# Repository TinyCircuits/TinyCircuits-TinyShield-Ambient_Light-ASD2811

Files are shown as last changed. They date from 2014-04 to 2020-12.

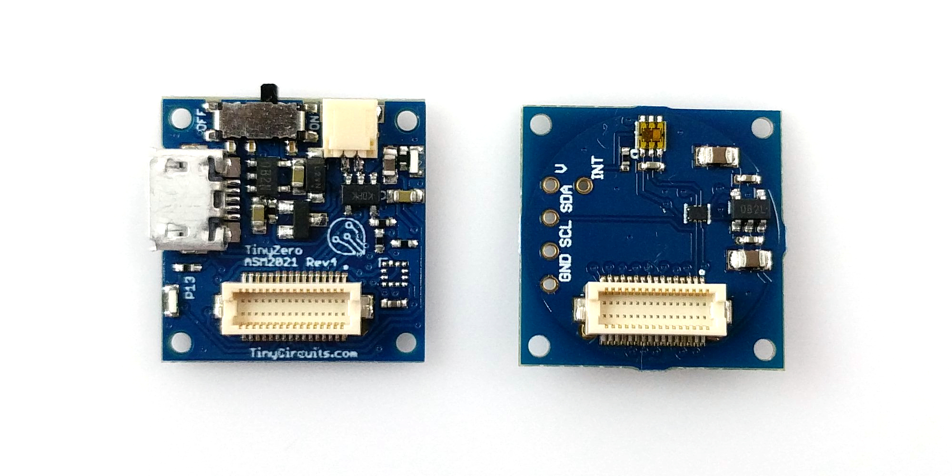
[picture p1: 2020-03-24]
images/ASD2811-R-Tutorial-Image-02.jpg

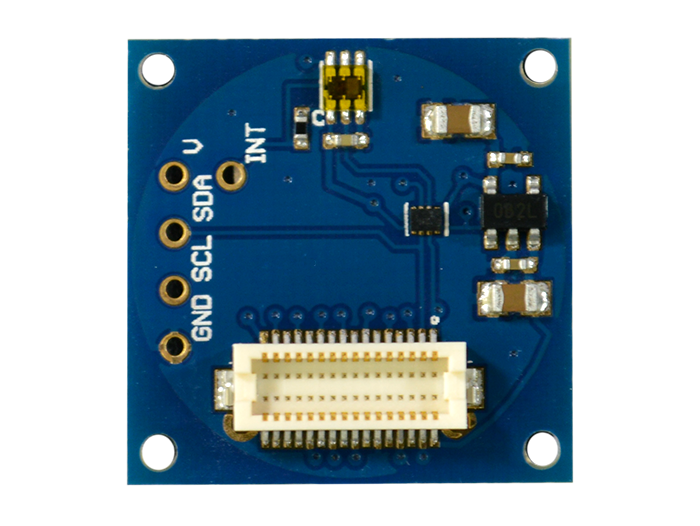
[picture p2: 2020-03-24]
images/ASD2811-R-Tutorial-Image-01.png

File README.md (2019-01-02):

# TinyCircuits TinyShield Ambient Light Sensor Board
# ASD2811 Rev2

The design files are located under design_files/ for the TinyCircuits ASD2811 Rev 2 PCB.  This is a TinyShield board (Square Version, 20mm x 20mm, or Circular 20mm diameter) that has a TAOS TSL2572 Ambient Light Sensor, local power supply and level shifters to connect between the TinyDuino and the accelerometer. 

Format is in Cadsoft Eagle format - Eagle version 6.2 was used for the original design.

For more infomation on this, check out the product page at TinyCircuits.com: https://tinycircuits.com/collections/sensors/products/ambient-light-tinyshield

#License:

Design by TinyCircuits.
All design files are released under the Creative Commons Attribution Share-Alike 3.0 License, see the following link for details: http://creativecommons.org/licenses/by-sa/3.0

All text above must be included in any redistribution or derived design

This project uses designs and concepts developed as part of the Arduino project and the LilyPad project.  The TinyCircuits design files themselves (schematics, PCB and libraries) are not directly derived from these works' design files and have been created new, however the concepts and basic architecture behind the TinyDuino and TinyLily products are derived and we thank the hard work of the organizations below for their contributions to open-source hardware:
  
Original Arduino Uno Design by Team Arduino

LilyPad Arduino Design by Leah Buechley and Sparkfun Electronics

Please support the open-source hardware community

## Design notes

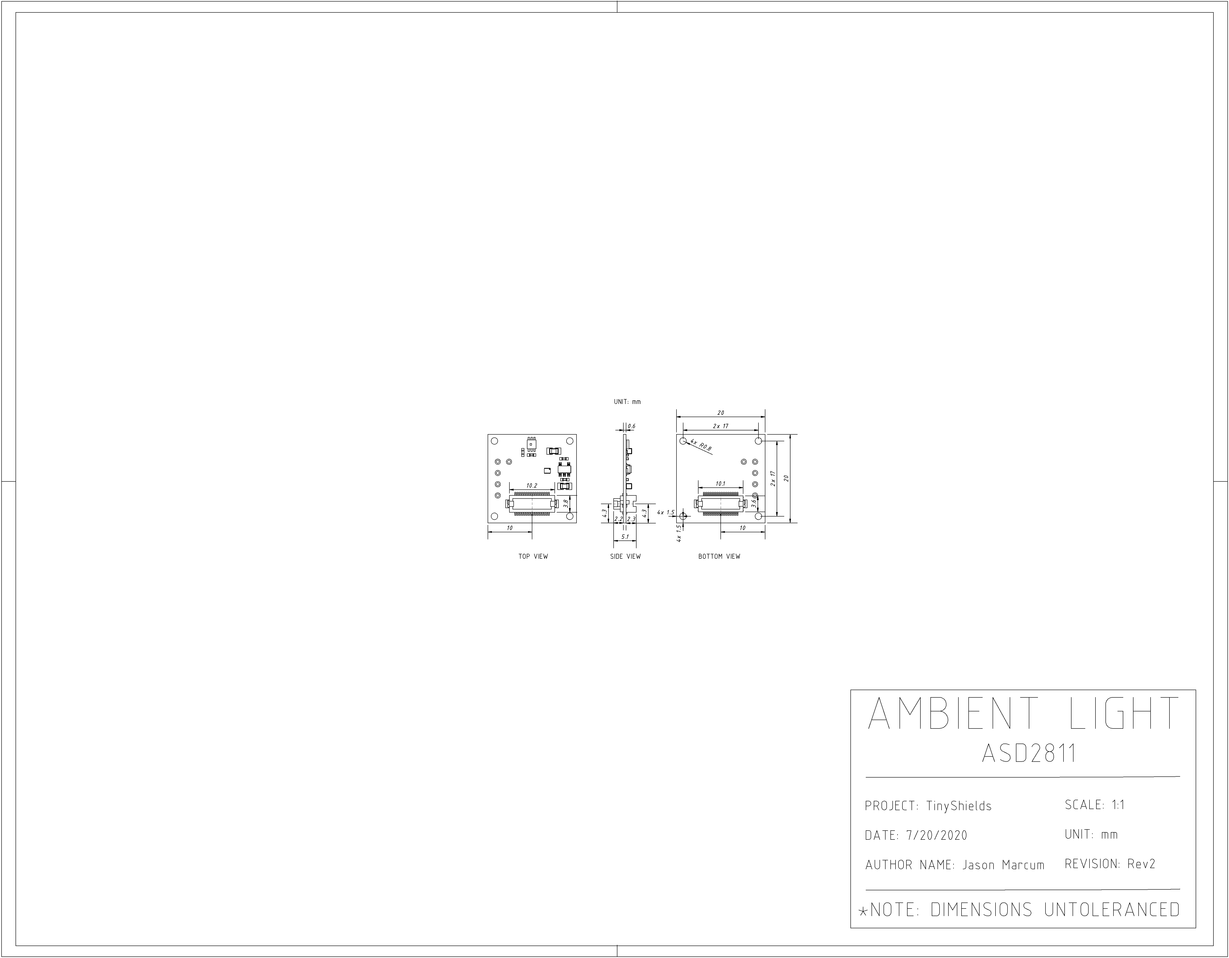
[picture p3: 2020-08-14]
cad/TinyShield_AMBIENT_LIGHT_ASD2811_REV2-DETAILED_DRAWING-PNG.png

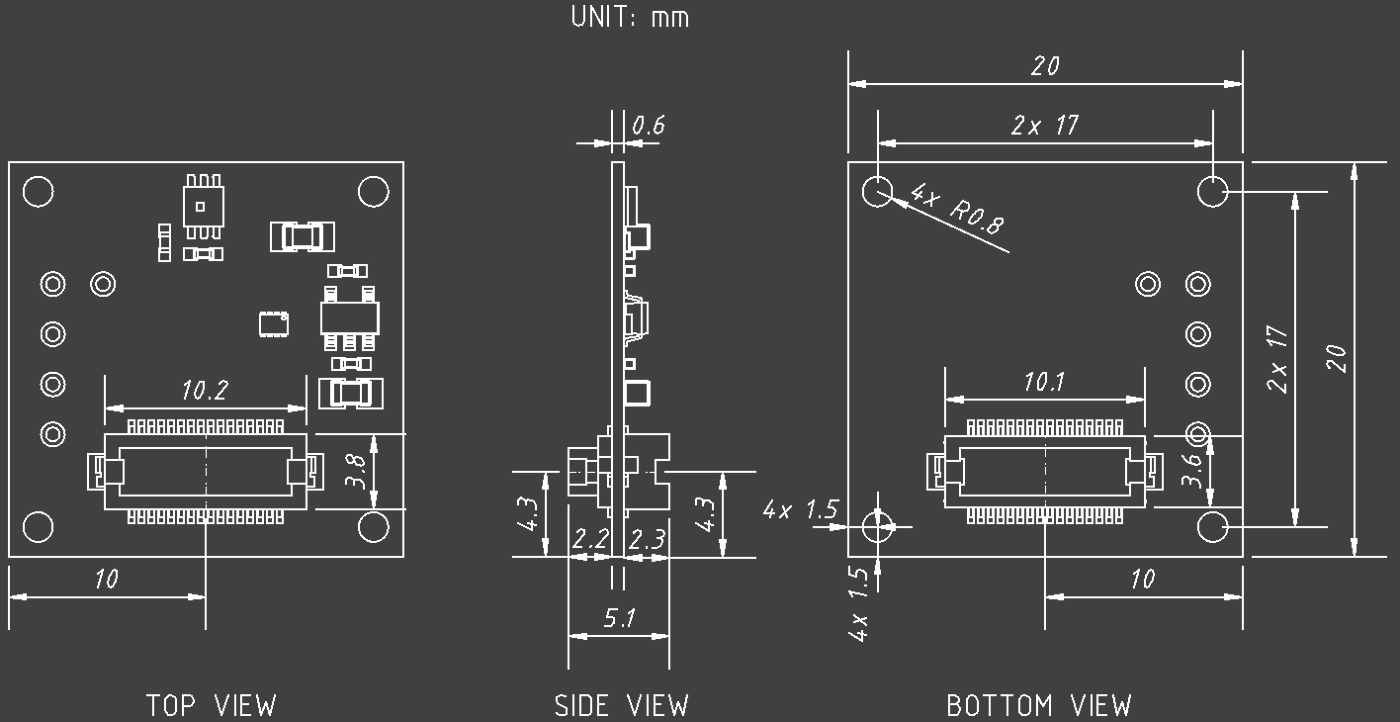
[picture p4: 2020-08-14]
cad/TinyShield_AMBIENT_LIGHT_ASD2811_REV2-DETAILED_DRAWING_COMPACT-PNG.png

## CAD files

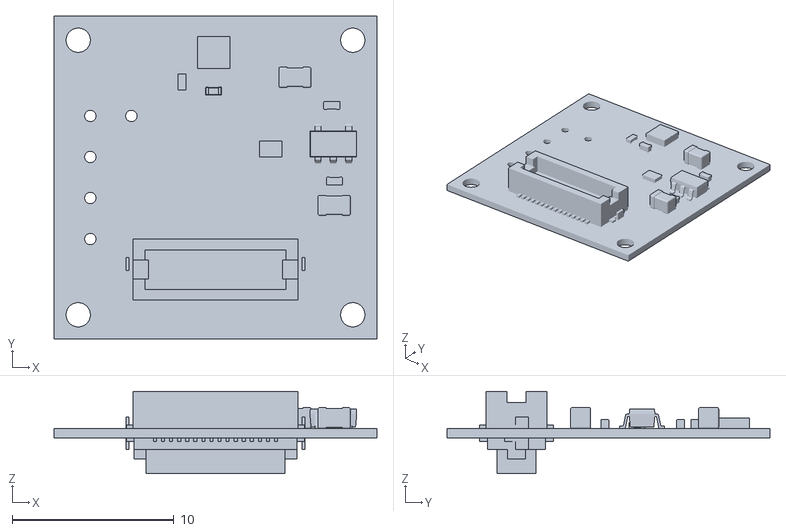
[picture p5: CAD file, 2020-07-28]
cad/TinyShield_AMBIENT_LIGHT_ASD2811_REV2-STL.stl
20.0 x 20.0 x 5.10

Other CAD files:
cad/TinyShield_AMBIENT_LIGHT_ASD2811_REV2-DETAILED_DRAWING-DXF.dxf

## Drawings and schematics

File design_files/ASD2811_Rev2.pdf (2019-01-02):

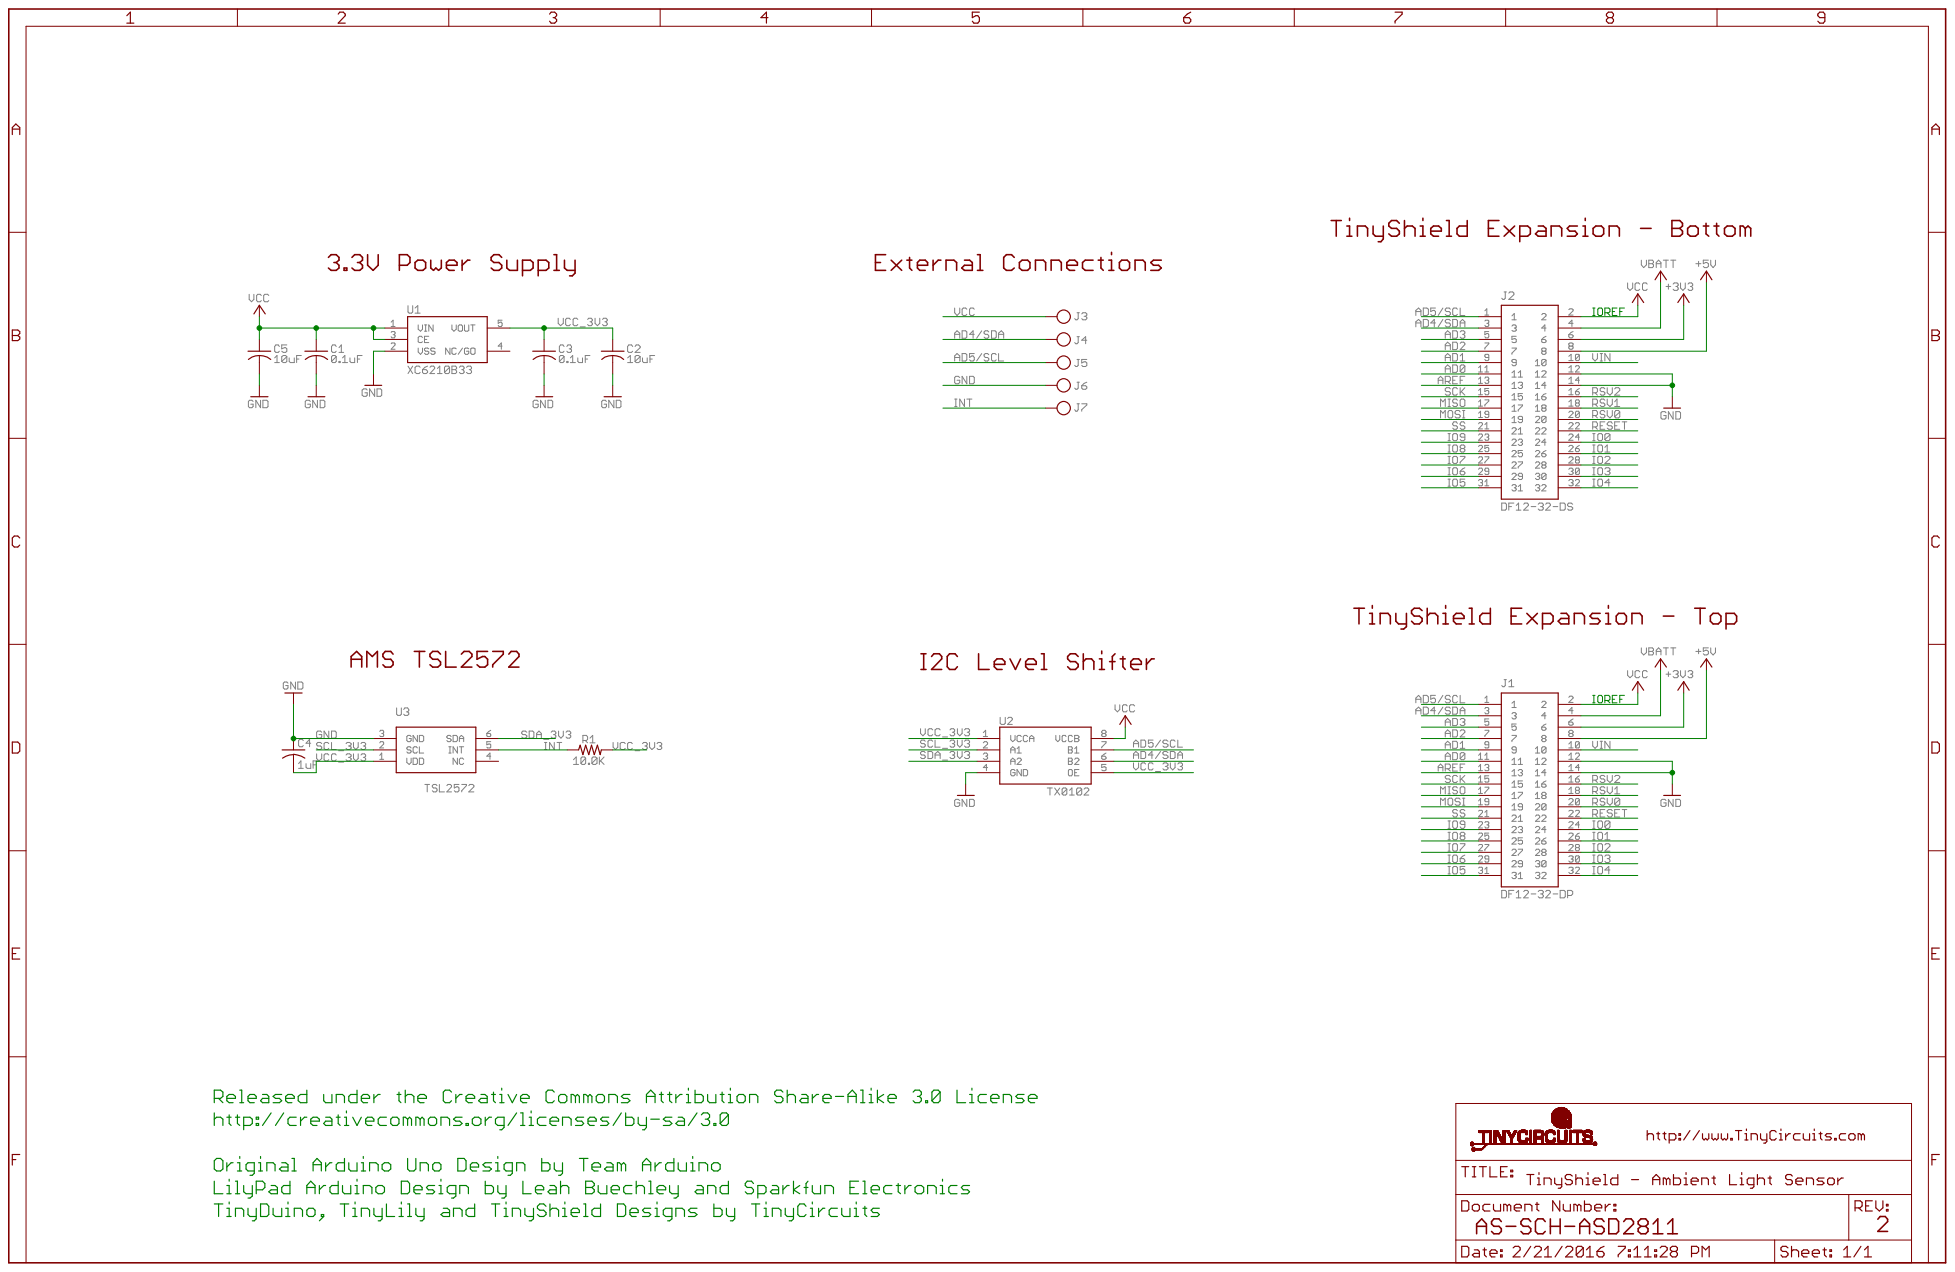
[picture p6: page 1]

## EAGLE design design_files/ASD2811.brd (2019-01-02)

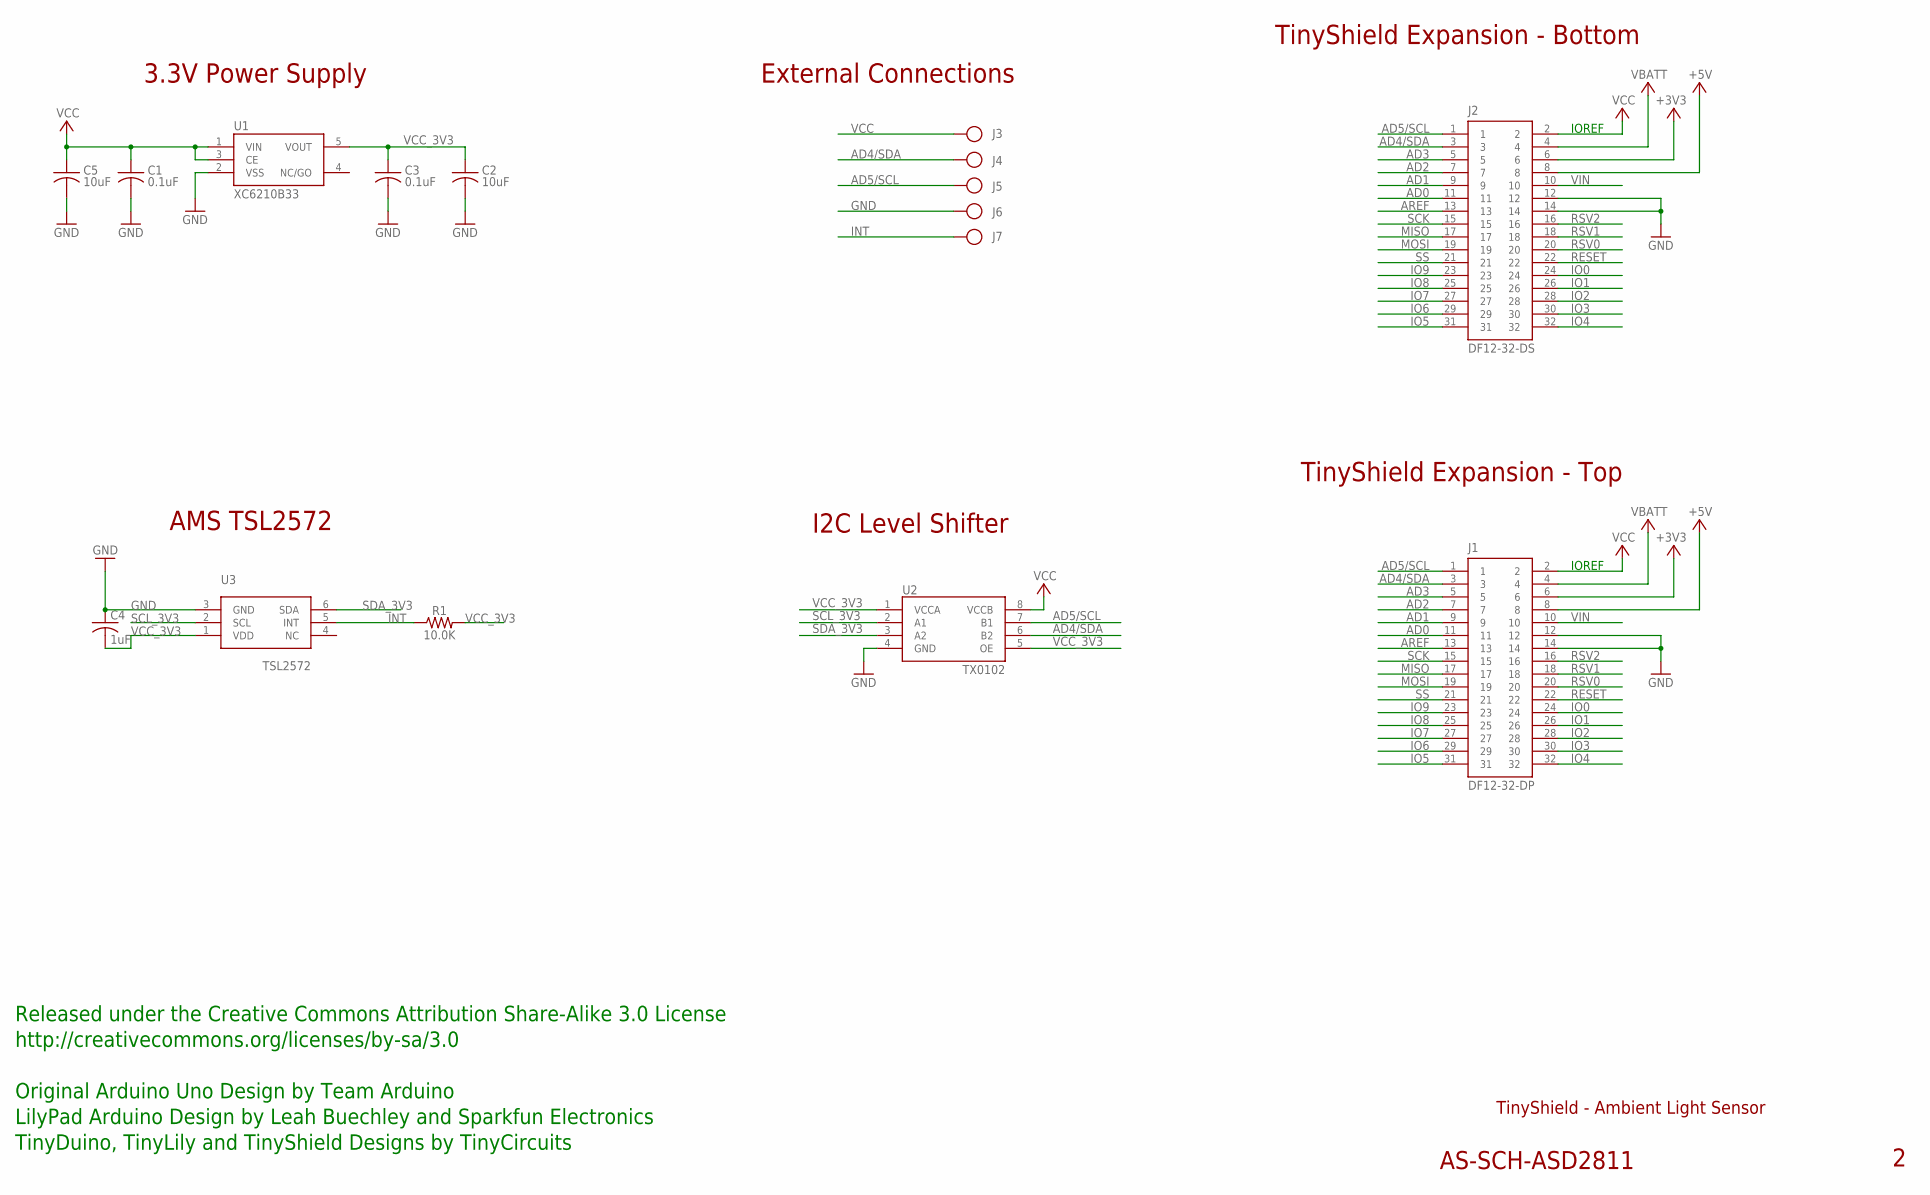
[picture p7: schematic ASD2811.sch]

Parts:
C1, C3: 0.1uF; C0402; PARTNO AS-ITM-00008
C2: 10uF; C0805; PARTNO AS-ITM-00045
C4: 1uF; C0402
C5: 10uF; C0805
J1: DF12-32-DP; PARTNO AS-ITM-00015
J2: DF12-32-DS; PARTNO AS-ITM-00012
J3, J4, J5, J6, J7: PIN_1X.1"; 1X.1"
R1: 10.0K; 0402
U1: XC6210B33; SOT-25
U2: TX0102; DQE(R-PX2SON-N8)
U3: TSL2572

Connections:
+3V3: J1.6, J2.6
+5V: J1.8, J2.8
AD0: J1.11, J2.11
AD1: J1.9, J2.9
AD2: J1.7, J2.7
AD3: J1.5, J2.5
AD4/SDA: J1.3, J2.3, J4.1, U2.6 (B2)
AD5/SCL: J1.1, J2.1, J5.1, U2.7 (B1)
AREF: J1.13, J2.13
GND: C1.2, C2.2, C3.2, C4.1, C5.2, J1.12, J1.14, J2.12, J2.14, J6.1, U1.2 (VSS), U2.4 (GND), U3.3 (GND)
INT: J7.1, R1.1, U3.5 (INT)
IO0: J1.24, J2.24
IO1: J1.26, J2.26
IO2: J1.28, J2.28
IO3: J1.30, J2.30
IO4: J1.32, J2.32
IO5: J1.31, J2.31
IO6: J1.29, J2.29
IO7: J1.27, J2.27
IO8: J1.25, J2.25
IO9: J1.23, J2.23
MISO: J1.17, J2.17
MOSI: J1.19, J2.19
RESET: J1.22, J2.22
RSV0: J1.20, J2.20
RSV1: J1.18, J2.18
RSV2: J1.16, J2.16
SCK: J1.15, J2.15
SCL_3V3: U2.2 (A1), U3.2 (SCL)
SDA_3V3: U2.3 (A2), U3.6 (SDA)
SS: J1.21, J2.21
VBATT: J1.4, J2.4
VCC: C1.1, C5.1, J1.2, J2.2, J3.1, U1.1 (VIN), U1.3 (CE), U2.8 (VCCB)
VCC_3V3: C2.1, C3.1, C4.2, R1.2, U1.5 (VOUT), U2.1 (VCCA), U2.5 (OE), U3.1 (VDD)
VIN: J1.10, J2.10

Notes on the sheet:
TinyShield Expansion - Bottom
TinyShield - Ambient Light Sensor
AS-SCH-ASD2811
TinyShield Expansion - Top
IOREF
Released under the Creative Commons Attribution Share-Alike 3.0 License
http://creativecommons.org/licenses/by-sa/3.0
LilyPad Arduino Design by Leah Buechley and Sparkfun Electronics
TinyDuino, TinyLily and TinyShield Designs by TinyCircuits
Original Arduino Uno Design by Team Arduino
External Connections
3.3V Power Supply
I2C Level Shifter
AMS TSL2572

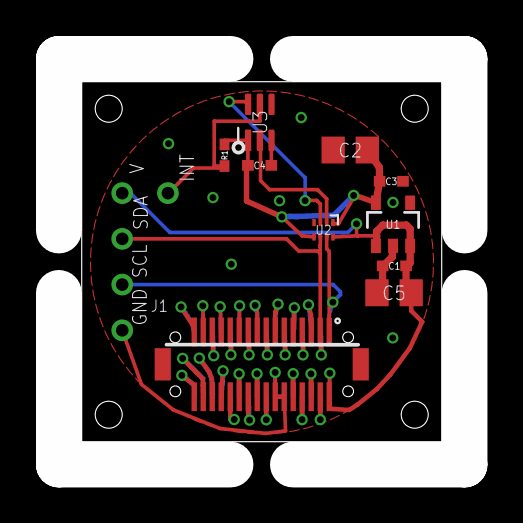
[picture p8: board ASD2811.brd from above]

Board: 2 copper layers, 20.0 x 20.0 mm, 17 parts (1 on the bottom side), 35 nets.

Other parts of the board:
U$1: DOCFIELD-TINYCIRCUITS-PCB

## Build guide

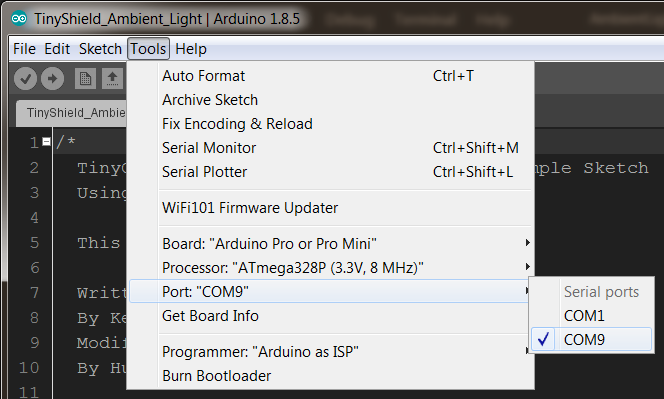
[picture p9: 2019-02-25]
images/ASD2811-Tutorial-Image-04.png

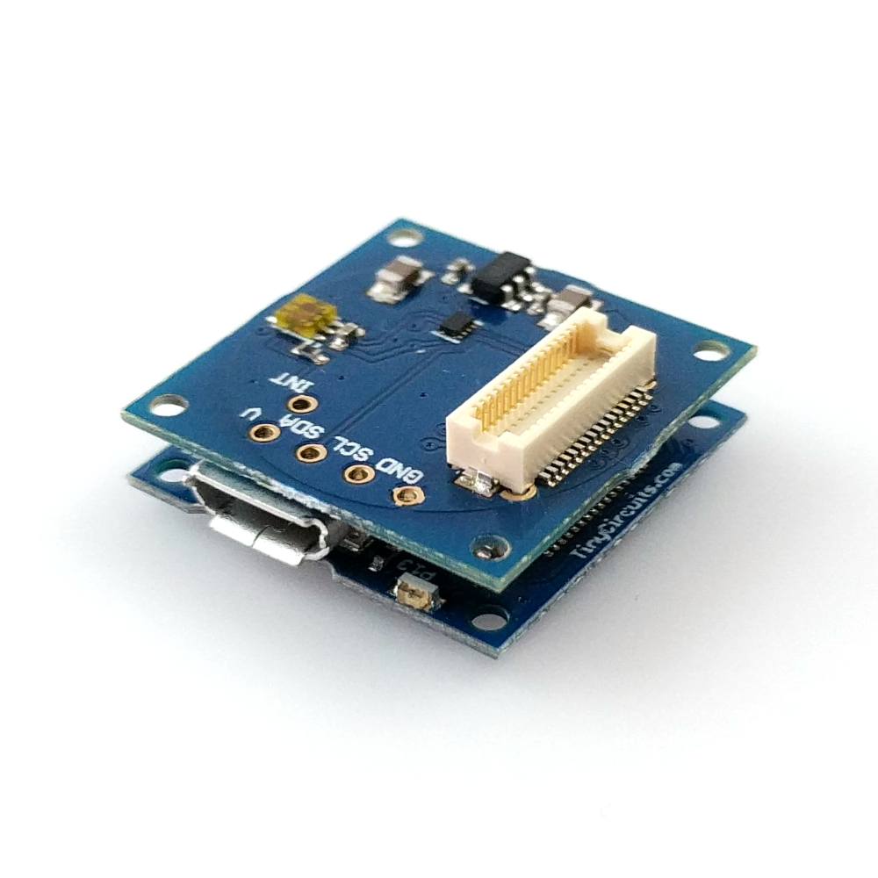
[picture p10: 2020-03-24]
images/ASD2811-R-Tutorial-Image-03.jpg

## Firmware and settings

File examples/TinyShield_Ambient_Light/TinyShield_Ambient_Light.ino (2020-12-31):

/*
  TinyCircuits Ambient Light TinyShield Example Sketch
  Using AMS TAOS TSL2572

  This example code is in the public domain.

  Written 25 October 2015
  By Ken Burns
  Modified 31 December 2020
  By Hunter Hykes

  https://TinyCircuits.com
*/

#include <Wire.h>
#include <TSL2572.h>      // For TSL2572 ambient light sensor

TSL2572 light_sensor;

#if defined (ARDUINO_ARCH_AVR)
#define SerialMonitorInterface Serial
#include <SoftwareSerial.h>
#elif defined(ARDUINO_ARCH_SAMD)
#define SerialMonitorInterface SerialUSB
#endif

int gain_val = 0;

void setup()
{
  Wire.begin();
  SerialMonitorInterface.begin(9600);

  //***************************************
  // SETTINGS & ADJUSTMENTS 
  //***************************************
  //  light_sensor.init(GAIN_1X);
  //  light_sensor.init(GAIN_8X);
    light_sensor.init(GAIN_16X);
  //  light_sensor.init(GAIN_120X);
}

void loop()
{
  float AmbientLightLux = light_sensor.readAmbientLight();
  SerialMonitorInterface.print("Lux: ");
  SerialMonitorInterface.println(AmbientLightLux);
  
  delay(1000);
}

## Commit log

2019-01-02 Update Rev and format
    [ASD2811.brd, ASD2811.sch]
2020-07-28 Add CAD data
    [TinyShield_AMBIENT_LIGHT_ASD2811_REV2-DETAILED_DRAWING-DXF.dxf, TinyShield_AMBIENT_LIGHT_ASD2811_REV2-STL.stl]
2020-08-14 Update CAD drawing
    [TinyShield_AMBIENT_LIGHT_ASD2811_REV2-DETAILED_DRAWING-DXF.dxf]
